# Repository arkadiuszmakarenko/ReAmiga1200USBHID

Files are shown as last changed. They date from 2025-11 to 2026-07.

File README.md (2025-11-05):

RISKYREA1200



## Build Status

Firmware builds are automatically generated for every commit. Pre-built binaries are available in the [GitHub Actions artifacts](https://github.com/arkadiuszmakarenko/RISKYREA1200/actions/workflows/build-firmware.yml).

For detailed information about the build process, see [BUILD.md](BUILD.md).

## About

Mouse Driver
Mouse driver has been provided by sq7bti.

I have used following other projects
- Mist (USB HID parser stack)
- Simon Inns smallymouse2 mouse quadrature encoding
- Amiga Keyboard handler: https://github.com/gianlucarenzi/stalker

This device supports following
- Mouse including scroll functionality (it supports 2 buttons only without a driver)
- Gamepad
- Keyboards

USB supports 4 port Hubs. Only good quality hubs work correctly.

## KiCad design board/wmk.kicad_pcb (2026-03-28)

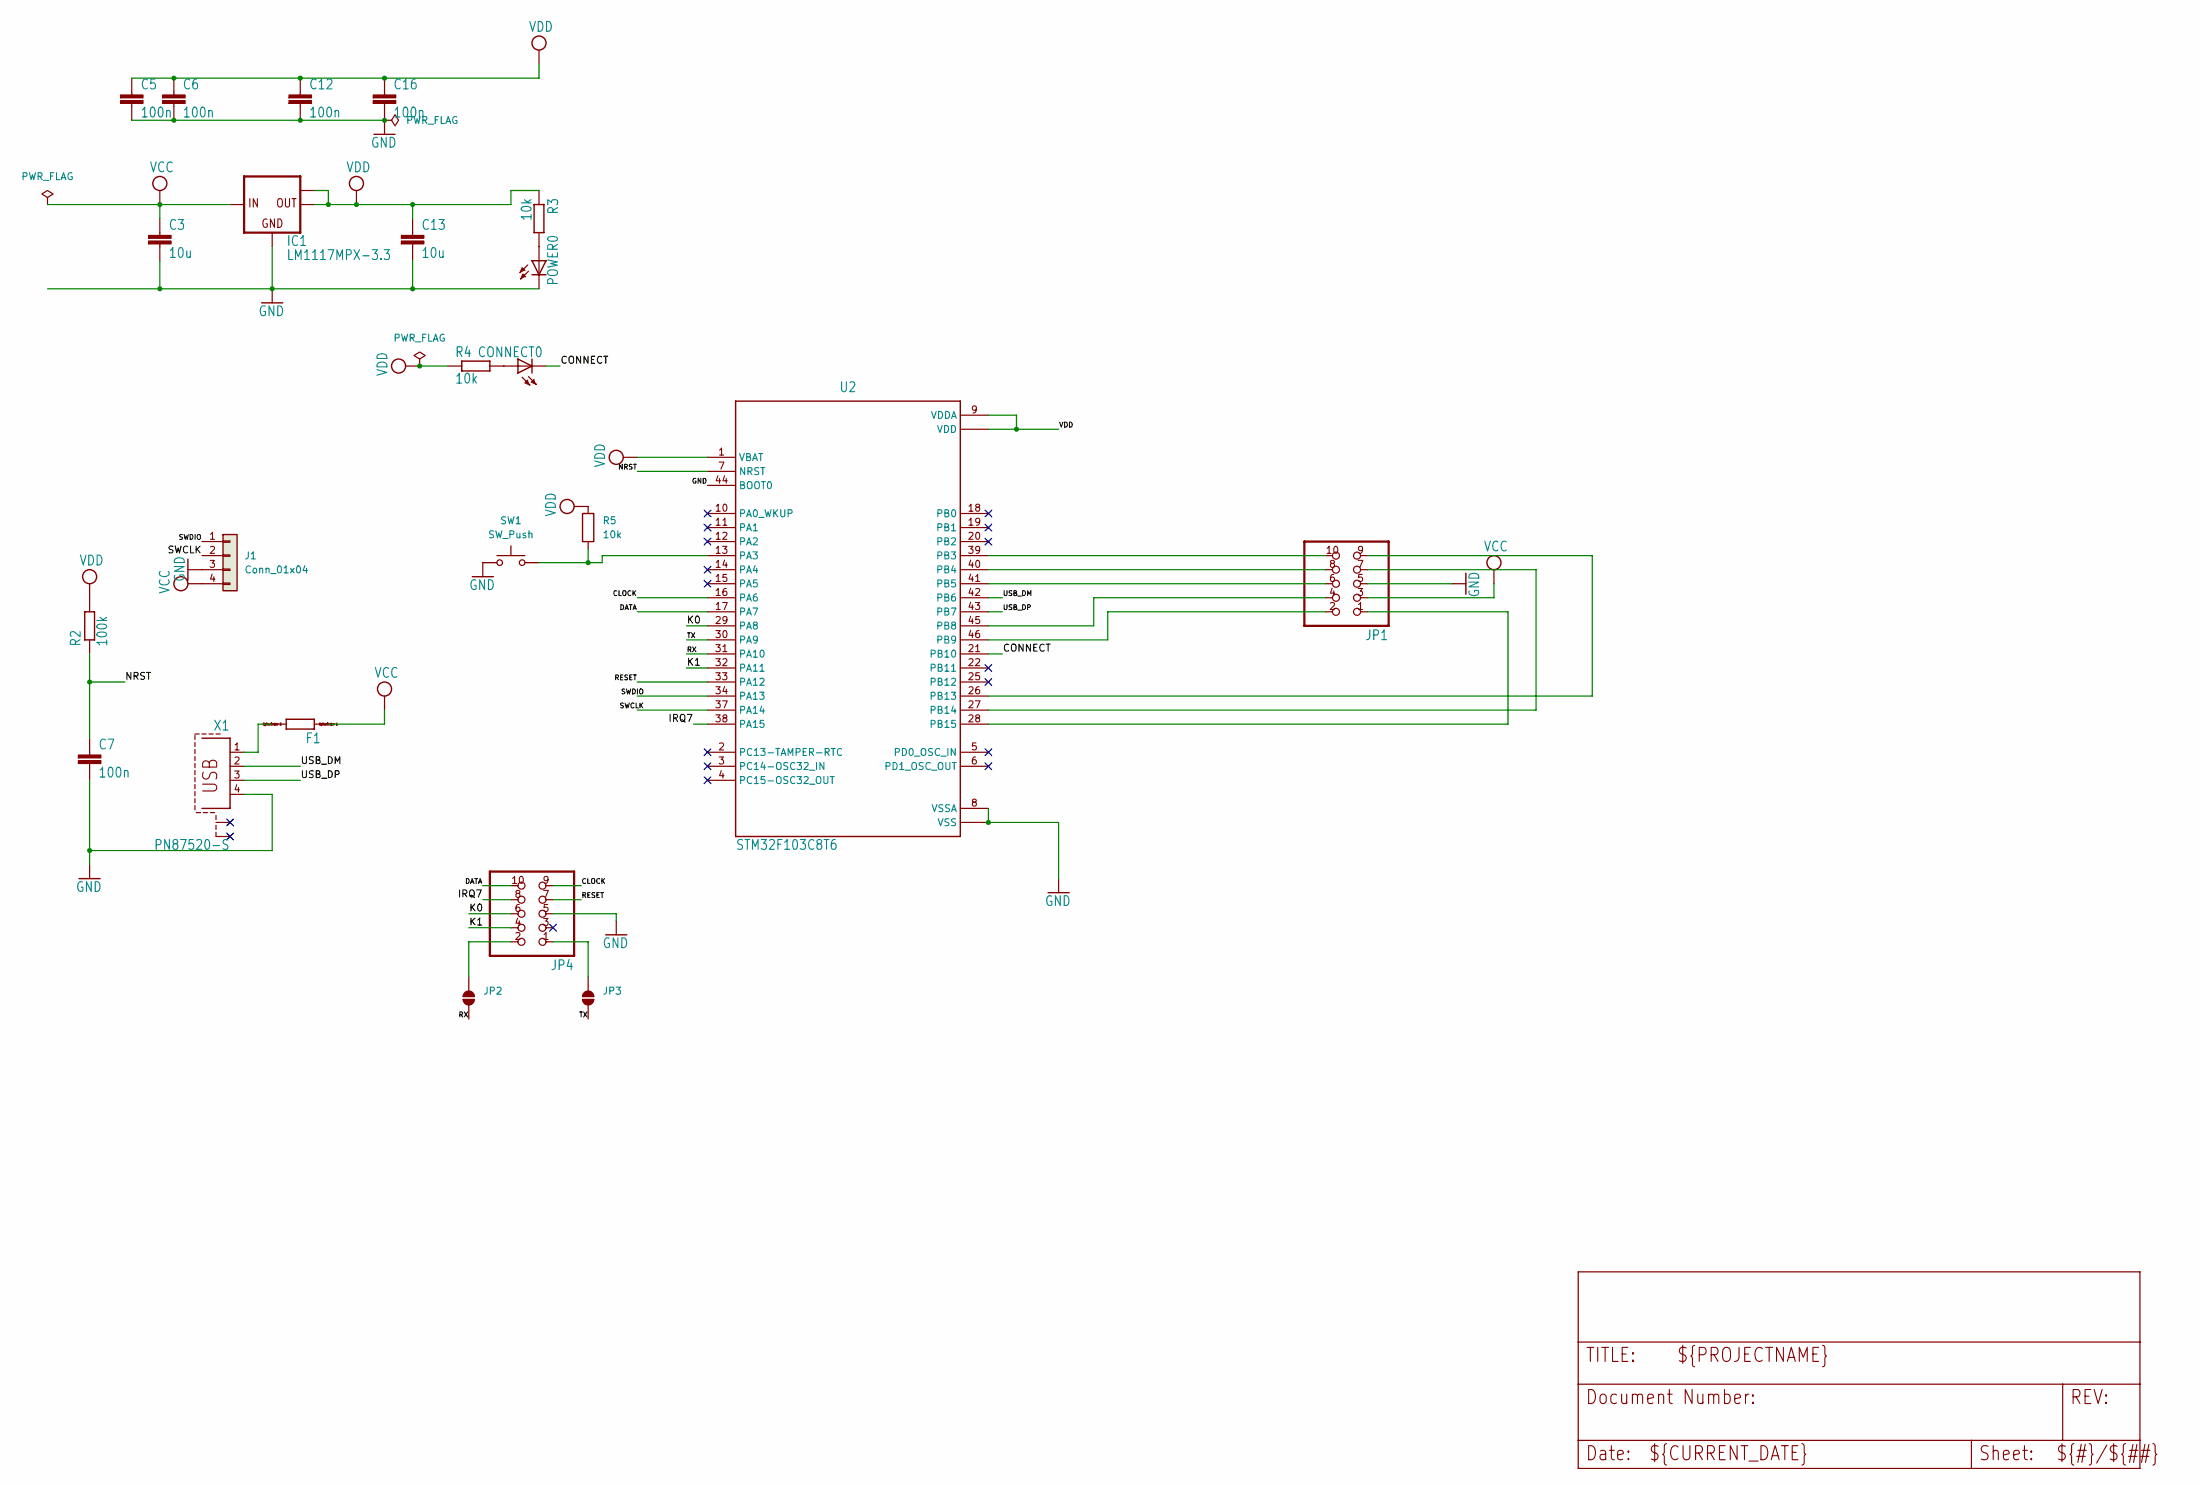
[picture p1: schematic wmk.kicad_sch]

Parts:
C3, C13: 10u; C1206
C5, C6, C7, C12, C16: 100n; C0603
CONNECT0: SML0805
F1: R1206
IC1: LM1117MPX-3.3; SOT223
J1: Conn_01x04; PinHeader_1x04_P2.54mm_Vertical
JP1, JP4: PinHeader_2x05_P2.54mm_Vertical
JP2, JP3: SolderJumper_2_Open
POWER0: SML0805
R2: 100k; R0603
R3, R4: 10k; R0603
R5: 10k; R_0603_1608Metric
SW1: SW_Push; SW_PUSH_6mm
U2: STM32F103C8T6; LQFP-48_7x7mm_P0.5mm
X1: PN87520-S

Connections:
/CLOCK: JP4.9, U2.16 (PA6)
/CONNECT: CONNECT0.C, U2.21 (PB10)
/DATA: JP4.10, U2.17 (PA7)
/IRQ7: JP4.8, U2.38 (PA15)
/K0: JP4.6, U2.29 (PA8)
/K1: JP4.4, U2.32 (PA11)
/NRST: C7.1, R2.1, U2.7 (NRST)
/RESET: JP4.7, U2.33 (PA12)
/RX: JP2.1 (A), U2.31 (PA10)
/SWCLK: J1.2, U2.37 (PA14)
/SWDIO: J1.1, U2.34 (PA13)
/TX: JP3.1 (A), U2.30 (PA9)
/USB_DM: U2.42 (PB6), X1.2
/USB_DP: U2.43 (PB7), X1.3
GND: C3.2, C5.2, C6.2, C7.2, C12.2, C13.2, C16.2, IC1.1 (GND), J1.3, JP1.5, JP4.5, POWER0.C, SW1.1, U2.8 (VSSA), U2.23 (VSS), U2.35 (VSS), U2.44 (BOOT0), U2.47 (VSS), X1.4; also elsewhere on the board
unnamed: CONNECT0.A, R4.2
unnamed: F1.2, X1.1
unnamed: JP2.2 (B), JP4.2
unnamed: JP3.2 (B), JP4.1
unnamed: POWER0.A, R3.2
unnamed 20: R5.2, SW1.2, U2.13 (PA3); also elsewhere on the board
unnamed: JP1.10, U2.39 (PB3)
unnamed: JP1.8, U2.40 (PB4)
unnamed: JP1.6, U2.41 (PB5)
unnamed: JP1.4, U2.45 (PB8)
unnamed: JP1.2, U2.46 (PB9)
unnamed: JP1.9, U2.26 (PB13)
unnamed: JP1.7, U2.27 (PB14)
unnamed: JP1.1, U2.28 (PB15)
VCC: C3.1, F1.1, IC1.3 (IN), J1.4, JP1.3
VDD: C5.1, C6.1, C12.1, C13.1, C16.1, IC1.2 (OUT), IC1.TAB (OUT1), R2.2, R3.1, R4.1, R5.1, U2.1 (VBAT), U2.9 (VDDA), U2.24 (VDD), U2.36 (VDD), U2.48 (VDD)

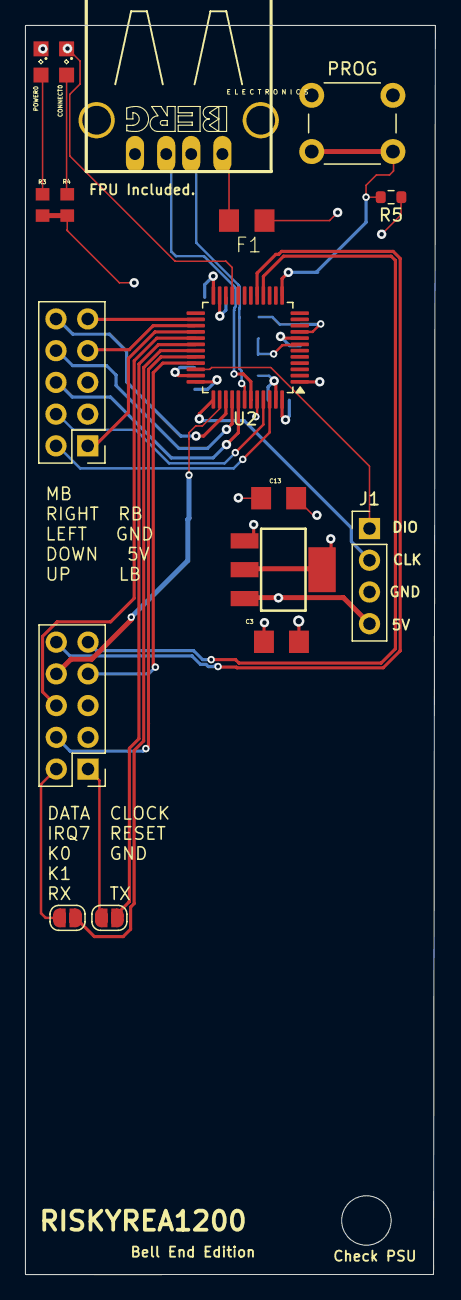
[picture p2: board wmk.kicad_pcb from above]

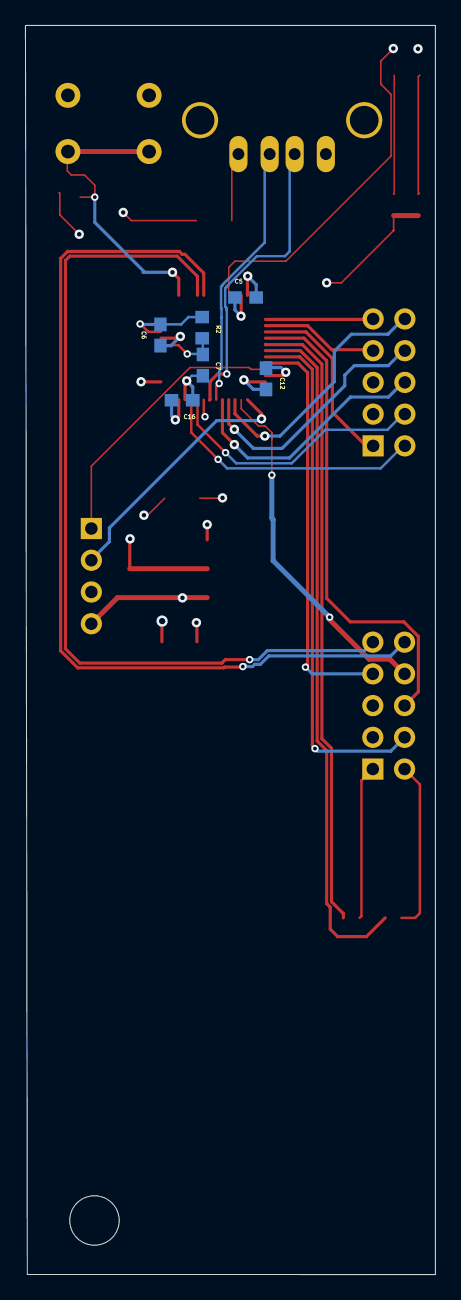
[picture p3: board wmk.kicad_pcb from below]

Board: 4 copper layers, 32.8 x 100.0 mm, 23 parts (6 on the bottom side), 31 nets.

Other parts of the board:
PROG: SW_Push; SW_PUSH_6mm

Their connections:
GND: PROG.1; also elsewhere on the board
unnamed 20: PROG.2; also elsewhere on the board

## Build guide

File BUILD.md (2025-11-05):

# Automated Build Process

This document describes the automated build process for the RISKYREA1200 firmware using GitHub Actions.

## Overview

The firmware is built automatically using a containerized environment based on Ubuntu 22.04. The workflow downloads and installs the WCH RISC-V toolchain, builds all firmware variants, and uploads the build artifacts for easy access.

## Workflow Triggers

The build workflow runs automatically on:
- Push to `main`, `master`, or `develop` branches
- Pull requests targeting `main`, `master`, or `develop` branches
- Manual trigger via the GitHub Actions UI (workflow_dispatch)

## Build Environment

- **Container**: Ubuntu 22.04
- **Toolchain**: WCH RISC-V toolchain V2.10 (Linux only, without IDE)
- **Toolchain Source**: https://github.com/arkadiuszmakarenko/WCHToolchain/releases/tag/ToolchainV210
- **Toolchain Path**: `/opt/riscv-toolchain/RISC-V Embedded GCC12/bin`
- **Build Tool**: GNU Make with parallel execution (`-j$(nproc)`)

## Build Process

The workflow performs the following steps:

1. **Repository Checkout**: Clones the repository code
2. **Install Dependencies**: Installs system build tools (build-essential, make, wget, xz-utils, tar)
3. **Download Toolchain**: Downloads WCH RISC-V toolchain V2.10 from GitHub release
4. **Verify Toolchain**: Checks toolchain installation and compiler execution
5. **Build Projects**: Builds all three firmware variants:
   - Bootloader (Debug build)
   - RISKYREA1200 (Release build)
   - RISKYREA1200Bootloader (Debug build)
6. **Create Combined Binary**: Combines bootloader and application into a single release binary
7. **Upload Artifacts**: Uploads all build outputs for download

## Build Artifacts

The following artifacts are generated and uploaded:

### Bootloader-Debug
- `Bootloader.bin` - Binary for bootloader (12KB at 0x00000000)
- `Bootloader.hex` - Intel HEX format
- `Bootloader.elf` - ELF executable with debug symbols

### RISKYREA1200-Release
- `RISKYREA1200.bin` - Standalone application binary (64KB at 0x00000000)
- `RISKYREA1200.hex` - Intel HEX format
- `RISKYREA1200.elf` - ELF executable

### RISKYREA1200Bootloader-Debug
- `RISKYREA1200Bootloader.bin` - Application binary for bootloader (52KB at 0x00003000)
- `RISKYREA1200Bootloader.hex` - Intel HEX format
- `RISKYREA1200Bootloader.elf` - ELF executable with debug symbols
- `RISKYREA.UPD` - Bootloader update file (copy of .bin for OTA updates)

### RISKYREA1200Release-Combined
- `RISKYREA1200Release.bin` - Combined bootloader + application (64KB total)
  - 0x00000000 - 0x00002FFF: Bootloader (12KB)
  - 0x00003000 - 0x0000FFFF: Application (52KB)

## Build Output Location

All build artifacts are stored in `firmware/build/` with the following structure:
```
firmware/build/
├── Bootloader/Debug/
│   ├── Bootloader.bin
│   ├── Bootloader.hex
│   ├── Bootloader.elf
│   ├── Bootloader.lst
│   └── Bootloader.map
├── RISKYREA1200/Release/
│   ├── RISKYREA1200.bin
│   ├── RISKYREA1200.hex
│   ├── RISKYREA1200.elf
│   ├── RISKYREA1200.lst
│   └── RISKYREA1200.map
├── RISKYREA1200Bootloader/Debug/
│   ├── RISKYREA1200Bootloader.bin
│   ├── RISKYREA1200Bootloader.hex
│   ├── RISKYREA1200Bootloader.elf
│   ├── RISKYREA1200Bootloader.lst
│   ├── RISKYREA1200Bootloader.map
│   └── RISKYREA.UPD
└── RISKYREA1200Release.bin
```

## Downloading Build Artifacts

1. Navigate to the GitHub Actions tab in the repository
2. Click on the latest successful workflow run
3. Scroll down to the "Artifacts" section
4. Download the desired artifact package
5. Extract the ZIP file to access the binaries

## Troubleshooting

### Toolchain Installation Issues

If the workflow fails during toolchain verification:
- Check that the toolchain URL is accessible
- Verify the toolchain directory structure matches expectations
- Ensure the compiler binary has execute permissions

The workflow includes diagnostic steps that will:
- List available directories if the toolchain path is not found
- Display available files if the compiler is missing
- Check compiler execution and display version information

### Build Failures

If a build step fails:
- Check the build logs for specific error messages
- Verify that all source files are present in the repository
- Ensure the Makefile configuration is correct for the toolchain path
- Confirm that the linker scripts are present and valid

### Makefile Configuration

The workflow uses the following Makefile parameters:
```bash
make PROJECT=<variant> BUILD_TYPE=<type> \
  MRS_TOOLCHAIN_ROOT=/opt/riscv-toolchain \
  -j$(nproc)
```

Where:
- `PROJECT`: Bootloader, RISKYREA1200, or RISKYREA1200Bootloader
- `BUILD_TYPE`: Release or Debug
- `MRS_TOOLCHAIN_ROOT`: Path to the extracted toolchain

## Local Build with Container

To replicate the CI build environment locally using Docker:

```bash
# Create a Dockerfile
cat > Dockerfile <<EOF
FROM ubuntu:22.04

RUN apt-get update && apt-get install -y \
    build-essential \
    make \
    wget \
    xz-utils \
    tar

RUN wget -q \
  https://github.com/arkadiuszmakarenko/WCHToolchain/releases/download/ToolchainV210/MRS_Toolchain_Linux_x64_V210.tar.xz \
  -O /tmp/toolchain.tar.xz && \
  mkdir -p /opt/riscv-toolchain && \
  tar -xf /tmp/toolchain.tar.xz -C /opt/riscv-toolchain --strip-components=1 && \
  rm /tmp/toolchain.tar.xz

WORKDIR /workspace
EOF

# Build and run
docker build -t riskyrea1200-build .
docker run -v $(pwd):/workspace riskyrea1200-build bash -c "cd firmware && make all-debug MRS_TOOLCHAIN_ROOT=/opt/riscv-toolchain"
```

## Toolchain Customization

The Makefile supports several environment variables for toolchain configuration:

- `MRS_TOOLCHAIN_ROOT`: Root directory of the MounRiver toolchain
- `TOOLCHAIN_VERSION`: Toolchain version directory (default: "RISC-V Embedded GCC12")
- `TOOLCHAIN_PREFIX`: Tool prefix (default: "riscv-wch-elf")
- `USE_SYSTEM_TOOLCHAIN=1`: Use system-installed toolchain instead

Example with custom toolchain path:
```bash
make PROJECT=RISKYREA1200 BUILD_TYPE=Release \
  MRS_TOOLCHAIN_ROOT=/custom/path/to/toolchain \
  -j$(nproc)
```

## Workflow Status Badge

Add this badge to your README.md to show the build status:

```markdown
[![Build Firmware](https://github.com/arkadiuszmakarenko/RISKYREA1200/actions/workflows/build-firmware.yml/badge.svg)](https://github.com/arkadiuszmakarenko/RISKYREA1200/actions/workflows/build-firmware.yml)
```

## References

- [WCH RISC-V Toolchain V2.10](https://github.com/arkadiuszmakarenko/WCHToolchain/releases/tag/ToolchainV210)
- [GitHub Actions Documentation](https://docs.github.com/en/actions)
- [WCH CH32V RISC-V MCU Resources](https://github.com/openwch)

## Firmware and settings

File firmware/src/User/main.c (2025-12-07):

/********************************** (C) COPYRIGHT *******************************
 * File Name          : main.c
 * Author             : WCH
 * Version            : V1.0.0
 * Date               : 2022/09/01
 * Description        : Main program body.
 *********************************************************************************
 * Copyright (c) 2021 Nanjing Qinheng Microelectronics Co., Ltd.
 * Azftware (modified or not) and binary are used for
 * microcontroller manufactured by Nanjing Qinheng Microelectronics.
 *******************************************************************************/

/*
 * @Note
 * This example demonstrates the process of enumerating the keyboard and mouse
 * by a USB host and obtaining data based on the polling time of the input endpoints
 * of the keyboard and mouse.
 * The USBFS port also supports enumeration of keyboard and mouse attached at tier
 * level 2(Hub 1).
 */

/*
 * @Note
 * The USBFS module uses the system clock as the clock source, so the SystemCoreClock can
 * only be set to 144MHz, 96MHz or 48MHz.
 */

/*******************************************************************************/
/* Header File */
#include "utils.h"
#include "tim.h"
#include "mouse.h"
#include "gpio.h"
#include "keyboard.h"
#include "usb_device_handler.h"

/*********************************************************************
 * @fn      main
 *
 * @brief   Main program.
 *
 * @return  none
 */
int main (void) {
    /* Initialize system configuration */
    Delay_Init();
    USART_Printf_Init (115200);
    DUG_PRINTF ("SystemClk:%d\r\n", SystemCoreClock);

    /* Initialize TIM3 */
    TIM3_Init (9, SystemCoreClock / 10000 - 1);
    DUG_PRINTF ("TIM3 Init OK!\r\n");

    /* Initialize USBFS host */
    usb_init();

    /* Initialize peripherals */
    DUG_PRINTF ("Initializing TIM2...\r\n");
    TIM2_Init();
    DUG_PRINTF ("TIM2 Init OK\r\n");
    
    DUG_PRINTF ("Initializing TIM4...\r\n");
    TIM4_Init();
    DUG_PRINTF ("TIM4 Init OK\r\n");
    
    DUG_PRINTF ("Initializing GPIO...\r\n");
    GPIO_Config();
    DUG_PRINTF ("GPIO Init OK\r\n");
    
    DUG_PRINTF ("Initializing Mouse...\r\n");
    InitMouse();
    DUG_PRINTF ("Mouse Init OK\r\n");
    
    /* Initialize Amiga keyboard interface */
    DUG_PRINTF ("Initializing Amiga keyboard...\r\n");
    amikb_startup();
    DUG_PRINTF ("Amiga keyboard initialized\r\n");
    
    DUG_PRINTF ("All systems initialized - entering main loop\r\n");

    while (1) {
        usb_process_devices();
    }
}

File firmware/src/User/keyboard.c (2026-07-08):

#include <string.h>
#include <stdlib.h>
#include <stdbool.h>
#include "keyboard.h"
#include "usb_keyboard.h"
#include "gpio.h"

/* ===== Type Definitions ===== */

typedef enum {
    LOCK_STATE_INACTIVE = 0,
    LOCK_STATE_ACTIVE = 1
} lock_state_e;

typedef struct {
    uint8_t caps_lock;
    uint8_t num_lock;
    uint8_t scroll_lock;
} lock_flags_t;

typedef struct {
    HID_KEYBD_Info_TypeDef previous_state;
    uint8_t last_transmitted_code;
    lock_flags_t lock_flags;
    bool is_ready;
} keyboard_state_t;

/* ===== Static State ===== */

static keyboard_state_t g_kbd_state = {
    .previous_state = {0},
    .last_transmitted_code = 0xFF,
    .lock_flags = {0},
    .is_ready = false};


/* ===== Static State ===== */

/* Replace O(n) table with a direct 256-entry lookup table for O(1) translation */
#define AMIGA_KEY_UNMAPPED 0xFF

static const uint8_t usb_to_amiga_lut[256] = {
    [0x00] = AMIGA_KEY_UNMAPPED, /* KEY_NONE */
    [0x01] = AMIGA_KEY_UNMAPPED,
    [0x02] = AMIGA_KEY_UNMAPPED,
    [0x03] = AMIGA_KEY_UNMAPPED,
    /* Letters */
    [0x04] = 0x20, /* A */
    [0x05] = 0x35, /* B */
    [0x06] = 0x33, /* C */
    [0x07] = 0x22, /* D */
    [0x08] = 0x12, /* E */
    [0x09] = 0x23, /* F */
    [0x0A] = 0x24, /* G */
    [0x0B] = 0x25, /* H */
    [0x0C] = 0x17, /* I */
    [0x0D] = 0x26, /* J */
    [0x0E] = 0x27, /* K */
    [0x0F] = 0x28, /* L */
    [0x10] = 0x37, /* M */
    [0x11] = 0x36, /* N */
    [0x12] = 0x18, /* O */
    [0x13] = 0x19, /* P */
    [0x14] = 0x10, /* Q */
    [0x15] = 0x13, /* R */
    [0x16] = 0x21, /* S */
    [0x17] = 0x14, /* T */
    [0x18] = 0x16, /* U */
    [0x19] = 0x34, /* V */
    [0x1A] = 0x11, /* W */
    [0x1B] = 0x32, /* X */
    [0x1C] = 0x15, /* Y */
    [0x1D] = 0x31, /* Z */
    /* Numbers */
    [0x1E] = 0x01, /* 1 */
    [0x1F] = 0x02, /* 2 */
    [0x20] = 0x03, /* 3 */
    [0x21] = 0x04, /* 4 */
    [0x22] = 0x05, /* 5 */
    [0x23] = 0x06, /* 6 */
    [0x24] = 0x07, /* 7 */
    [0x25] = 0x08, /* 8 */
    [0x26] = 0x09, /* 9 */
    [0x27] = 0x0A, /* 0 */
    /* Common keys */
    [0x28] = 0x44,               /* Enter */
    [0x29] = 0x45,               /* Escape */
    [0x2A] = 0x41,               /* Backspace */
    [0x2B] = 0x42,               /* Tab */
    [0x2C] = 0x40,               /* Space */
    [0x2D] = 0x0B,               /* -_ */
    [0x2E] = 0x0C,               /* =+ */
    [0x2F] = 0x1A,               /* [{ */
    [0x30] = 0x1B,               /* ]} */
    [0x31] = 0x0D,               /* \| */
    [0x32] = AMIGA_KEY_UNMAPPED, /* Non-US */
    [0x33] = 0x29,               /* ;: */
    [0x34] = 0x2A,               /* '" */
    [0x35] = 0x00,               /* `~ */
    [0x36] = 0x38,               /* ,< */
    [0x37] = 0x39,               /* .> */
    [0x38] = 0x3A,               /* /? */
    [0x39] = 0x62,               /* Caps Lock */
    /* Function keys */
    [0x3A] = 0x50,
    [0x3B] = 0x51,
    [0x3C] = 0x52,
    [0x3D] = 0x53,
    [0x3E] = 0x54,
    [0x3F] = 0x55,
    [0x40] = 0x56,
    [0x41] = 0x57,
    [0x42] = 0x58,
    [0x43] = 0x59,
    [0x44] = AMIGA_KEY_UNMAPPED,
    [0x45] = 0x5F,
    /* Print/Scroll/Pause */
    [0x46] = 0x0E,
    [0x47] = 0x1C,
    [0x48] = 0x2C,
    /* Navigation cluster */
    [0x49] = 0x4B,
    [0x4A] = 0x3B,
    [0x4B] = 0x3F,
    [0x4C] = 0x46,
    [0x4D] = 0x49,
    [0x4E] = 0x1F,
    [0x4F] = 0x4E,
    [0x50] = 0x4F,
    [0x51] = 0x4D,
    [0x52] = 0x4C,
    /* Keypad */
    [0x53] = 0x68,
    [0x54] = 0x5C,
    [0x55] = 0x5D,
    [0x56] = 0x4A,
    [0x57] = 0x5E,
    [0x58] = 0x43,
    [0x59] = 0x1D,
    [0x5A] = 0x1E,
    [0x5B] = 0x1F,
    [0x5C] = 0x2D,
    [0x5D] = 0x2E,
    [0x5E] = 0x2F,
    [0x5F] = 0x3D,
    [0x60] = 0x3E,
    [0x61] = 0x3F,
    [0x62] = 0x0F,
    [0x63] = 0x3C,
    /* Misc */
    [0x64] = AMIGA_KEY_UNMAPPED,
    [0x65] = 0x5F,
    [0x85] = 0x38,
    [0x88] = 0x30,
    [0x9E] = 0x2B,
    /* Modifiers */
    [0xE0] = 0x63,
    [0xE1] = 0x60,
    [0xE2] = 0x64,
    [0xE3] = 0x66,
    [0xE4] = AMIGA_KEY_UNMAPPED,
    [0xE5] = 0x61,
    [0xE6] = 0x65,
    [0xE7] = 0x67,
};

static inline uint8_t translate_usb_to_amiga (uint8_t usb_key) {
    uint8_t amiga = usb_to_amiga_lut[usb_key];
    return (amiga == AMIGA_KEY_UNMAPPED) ? usb_key : amiga;
}

static void handle_ctrl_f11 (void) {
    GPIO_WriteBit (IRQ7_Port, IRQ7_Pin, Bit_RESET);
    Delay_Us (500);
    GPIO_WriteBit (IRQ7_Port, IRQ7_Pin, Bit_SET);
}

static void handle_ctrl_f12 (void) {
    /* Cycle through states 00, 01, 10, 11 on each call.
       bit0 -> K0, bit1 -> K1. */
    static uint8_t kstate = 0;
    kstate = (kstate + 1) & 0x03;

    const BitAction k0_level = (kstate & 0x01) ? Bit_RESET : Bit_SET;
    const BitAction k1_level = (kstate & 0x02) ? Bit_RESET : Bit_SET;

    GPIO_WriteBit (K0_Port, K0_Pin, k0_level);
    GPIO_WriteBit (K1_Port, K1_Pin, k1_level);

    Delay_Us (200);

    amikb_reset();
}
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

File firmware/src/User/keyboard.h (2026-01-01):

#ifndef __AMIGA_INCLUDED__
#define __AMIGA_INCLUDED__

#include <stdint.h>
#include <inttypes.h>
#include <stdbool.h>
#include "gpio.h"
#include "usb_keyboard.h"

/* Constants */
#define KEY_PRESSED_MAX 6
#define KEYCODE_TAB_SIZE 0x70

/* Timing constants (microseconds) */
#define TIMING_SYNC_DELAY_US        200
#define TIMING_HANDSHAKE_US         100
#define TIMING_BIT_DELAY_US         10
#define TIMING_CLOCK_PULSE_US       10
#define TIMING_DATA_SETUP_US        10

/* USB HID Key Codes */
#define KEY_NONE                    0x00
#define KEY_ERRORROLLOVER           0x01
#define KEY_POSTFAIL                0x02
#define KEY_ERRORUNDEFINED          0x03
#define KEY_A                       0x04
#define KEY_B                       0x05
#define KEY_C                       0x06
#define KEY_D                       0x07
#define KEY_E                       0x08
#define KEY_F                       0x09
#define KEY_G                       0x0A
#define KEY_H                       0x0B
#define KEY_I                       0x0C
#define KEY_J                       0x0D
#define KEY_K                       0x0E
#define KEY_L                       0x0F
#define KEY_M                       0x10
#define KEY_N                       0x11
#define KEY_O                       0x12
#define KEY_P                       0x13
#define KEY_Q                       0x14
#define KEY_R                       0x15
#define KEY_S                       0x16
#define KEY_T                       0x17
#define KEY_U                       0x18
#define KEY_V                       0x19
#define KEY_W                       0x1A
#define KEY_X                       0x1B
#define KEY_Y                       0x1C
#define KEY_Z                       0x1D
#define KEY_1_EXCLAMATION_MARK      0x1E
#define KEY_2_AT                    0x1F
#define KEY_3_NUMBER_SIGN           0x20
#define KEY_4_DOLLAR                0x21
#define KEY_5_PERCENT               0x22
#define KEY_6_CARET                 0x23
#define KEY_7_AMPERSAND             0x24
#define KEY_8_ASTERISK              0x25
#define KEY_9_OPARENTHESIS          0x26
#define KEY_0_CPARENTHESIS          0x27
#define KEY_ENTER                   0x28
#define KEY_ESCAPE                  0x29
#define KEY_BACKSPACE               0x2A
#define KEY_TAB                     0x2B
#define KEY_SPACEBAR                0x2C
#define KEY_MINUS_UNDERSCORE        0x2D
#define KEY_EQUAL_PLUS              0x2E
#define KEY_OBRACKET_AND_OBRACE     0x2F
#define KEY_CBRACKET_AND_CBRACE     0x30
#define KEY_BACKSLASH_VERTICAL_BAR  0x31
#define KEY_NONUS_NUMBER_SIGN_TILDE 0x32
#define KEY_SEMICOLON_COLON         0x33
#define KEY_SINGLE_AND_DOUBLE_QUOTE 0x34
#define KEY_GRAVE_ACCENT_AND_TILDE  0x35
#define KEY_COMMA_AND_LESS          0x36
#define KEY_DOT_GREATER             0x37
#define KEY_SLASH_QUESTION          0x38
#define KEY_CAPS_LOCK               0x39
#define KEY_F1                      0x3A
#define KEY_F2                      0x3B
#define KEY_F3                      0x3C
#define KEY_F4                      0x3D
#define KEY_F5                      0x3E
#define KEY_F6                      0x3F
#define KEY_F7                      0x40
#define KEY_F8                      0x41
#define KEY_F9                      0x42
#define KEY_F10                     0x43
#define KEY_F11                     0x44
#define KEY_F12                     0x45
#define KEY_PRINTSCREEN             0x46
#define KEY_SCROLL_LOCK             0x47
#define KEY_PAUSE                   0x48
#define KEY_INSERT                  0x49
#define KEY_HOME                    0x4A
#define KEY_PAGEUP                  0x4B
#define KEY_DELETE                  0x4C
#define KEY_END1                    0x4D
#define KEY_PAGEDOWN                0x4E
#define KEY_RIGHTARROW              0x4F
#define KEY_LEFTARROW               0x50
#define KEY_DOWNARROW               0x51
#define KEY_UPARROW                 0x52
#define KEY_KEYPAD_NUM_LOCK_AND_CLEAR       0x53
#define KEY_KEYPAD_SLASH                    0x54
#define KEY_KEYPAD_ASTERIKS                 0x55
#define KEY_KEYPAD_MINUS                    0x56
#define KEY_KEYPAD_PLUS                     0x57
#define KEY_KEYPAD_ENTER                    0x58
#define KEY_KEYPAD_1_END                    0x59
#define KEY_KEYPAD_2_DOWN_ARROW             0x5A
#define KEY_KEYPAD_3_PAGEDN                 0x5B
#define KEY_KEYPAD_4_LEFT_ARROW             0x5C
#define KEY_KEYPAD_5                        0x5D
#define KEY_KEYPAD_6_RIGHT_ARROW            0x5E
#define KEY_KEYPAD_7_HOME                   0x5F
#define KEY_KEYPAD_8_UP_ARROW               0x60
#define KEY_KEYPAD_9_PAGEUP                 0x61
#define KEY_KEYPAD_0_INSERT                 0x62
#define KEY_KEYPAD_DECIMAL_SEPARATOR_DELETE 0x63
#define KEY_NONUS_BACK_SLASH_VERTICAL_BAR   0x64
#define KEY_APPLICATION                     0x65
#define KEY_POWER                           0x66
#define KEY_KEYPAD_EQUAL                    0x67
#define KEY_F13                             0x68
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

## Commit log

2024-05-11 Board and Firmware
    [wmk-B_Cu.gbr, wmk-B_Mask.gbr, wmk-B_Paste.gbr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]
2024-05-11 tidy up
    [wmk-B_Cu.gbr, wmk-B_Mask.gbr, wmk-B_Paste.gbr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]
2025-11-01 initial version
    [wmk-B_Cu.gbr, wmk-B_Mask.gbr, wmk-B_Paste.gbr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]
2025-11-02 Bootloader ready, basic init of app device done.
2025-11-10 PCB changes and gerbers
    [wmk-B_Mask.gbr, wmk-B_Paste.gbr, wmk-B_Silkscreen.gbr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]
2026-03-28 Board review
    [wmk-B_Mask.gbr, wmk-B_Paste.gbr, wmk-B_Silkscreen.gbr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]
2026-03-28 Update footprint properties for solder jumpers in schematic
    [wmk.kicad_sch]
2026-07-08 Increase reset pulse count in amikb_reset function
    Increased the reset pulse count from 10 to 100.
    [keyboard.c]
